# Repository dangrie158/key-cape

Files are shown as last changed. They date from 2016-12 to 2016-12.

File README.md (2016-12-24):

# KeyCape

a simple UI extension for your PC / Mac. 

KeyCape offers the following Hardware I/Os:

* Cherry MX Switch with LED
* Encoder with Button
* 4 general purpose LEDs

As the firmware is still in development I'm not sure yet how to implement all I/O in a good way. Probably a HID Keyboard with the Cherry Switch acting as a ESC button (so vim is usable again for the new Mac Books with touchbar) and the encoder as vol up/down.

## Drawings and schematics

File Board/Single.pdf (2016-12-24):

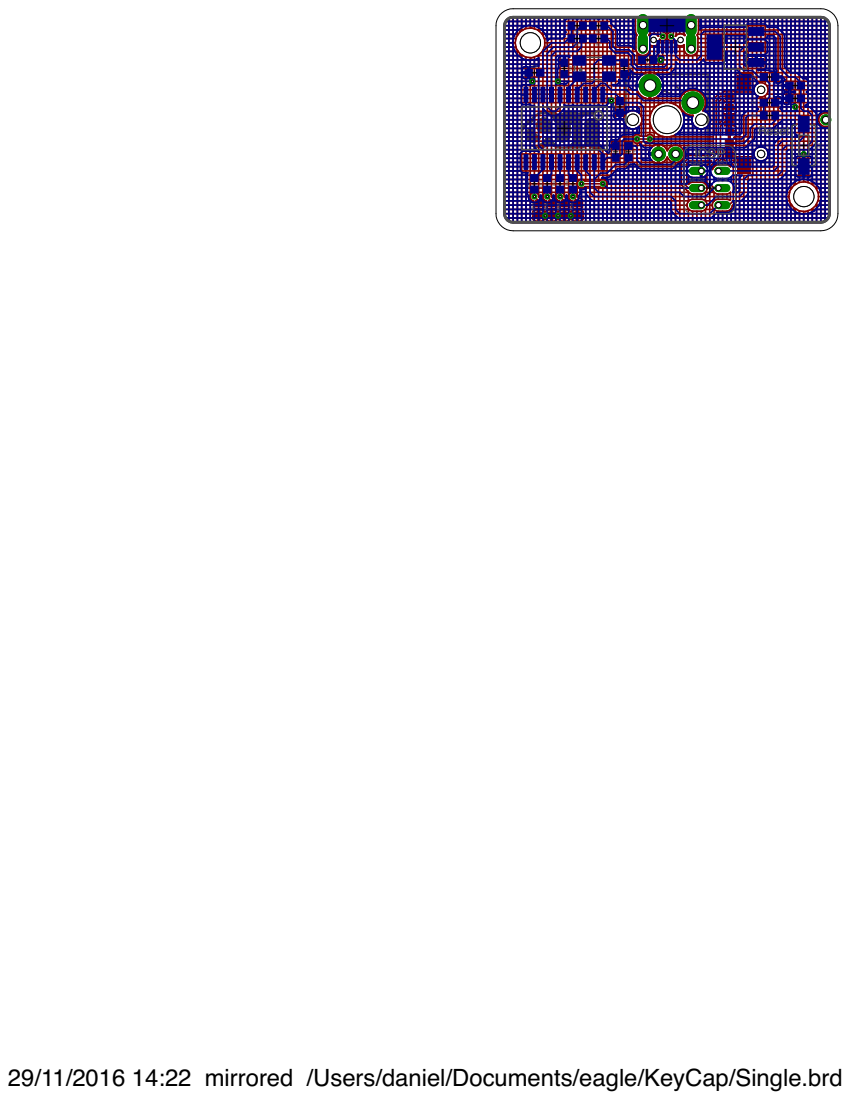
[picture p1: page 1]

RST MOSI VCC GND

29/11/2016 14:22 mirrored /Users/daniel/Documents/eagle/KeyCap/Single.brd

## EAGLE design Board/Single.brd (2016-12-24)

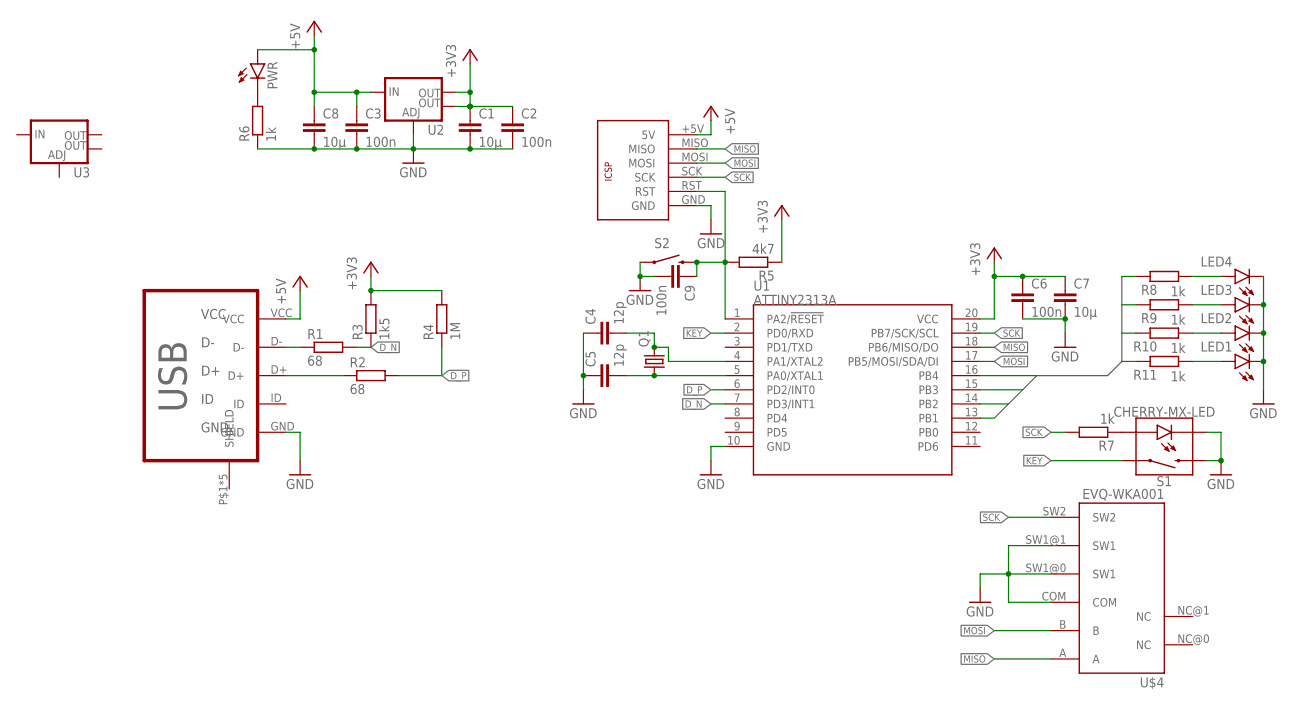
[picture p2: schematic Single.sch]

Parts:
C1, C7, C8: 10µ; C0603
C2, C3, C6, C9: 100n; C0603
C4, C5: 12p; C0603
LED1, LED2, LED3, LED4: LED0603; LED-0603
PWR: LED0603; LED-0603
Q1: CRYSTALCTS406; CTS406
R1, R2: 68; R0603
R3: 1k5; R0603
R4: 1M; R0603
R5: 4k7; R0603
R6, R7, R8, R9, R10, R11: 1k; R0603
S1: CHERRY-MX-LED
S2: SWITCH-MOMENTARY-2SMD-1101NE; TACTILE-SWITCH-1101NE
U1: ATTINY2313A; SOP20W
U2, U3: V_REG_LM1117SOT223; SOT223
U$1: ICSPTHROUGHHOLE; ICSP-THROUGHHOLE
U$2: MICRO-USB-B; MICRO_USB_4_LEGS
U$4: EVQ-WKA001

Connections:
+3V3: C1.1, C2.1, C6.1, C7.1, R3.2, R4.2, R5.1, U1.20 (VCC), U2.2 (OUT), U2.4 (OUT)
+5V: C3.1, C8.1, PWR.A, U2.3 (IN), U$1.+5V (5V), U$2.VCC
DUSB_N: R1.1, U$2.D-
DUSB_P: R2.1, U$2.D+
D_N: R1.2, R3.1, U1.7 (PD3/INT1)
D_P: R2.2, R4.1, U1.6 (PD2/INT0)
GND: C1.2, C2.2, C3.2, C4.1, C5.1, C6.2, C7.2, C8.2, C9.2, LED1.C, LED2.C, LED3.C, LED4.C, R6.1, S1.K (C), S1.S2, S2.1, U1.10 (GND), U2.1 (ADJ), U$1.GND, U$2.GND, U$4.COM, U$4.SW1@0 (SW1), U$4.SW1@1 (SW1)
KEY: S1.S1, U1.2 (PD0/RXD)
LED1: R11.2, U1.13 (PB1)
LED2: R10.2, U1.14 (PB2)
LED3: R9.2, U1.15 (PB3)
LED4: R8.2, U1.16 (PB4)
MISO: U1.18 (PB6/MISO/DO), U$1.MISO, U$4.A
MOSI: U1.17 (PB5/MOSI/SDA/DI), U$1.MOSI, U$4.B
unnamed: C4.2, Q1.3 (2), U1.4 (PA1/XTAL2)
unnamed: C5.2, Q1.1, U1.5 (PA0/XTAL1)
unnamed: PWR.C, R6.2
unnamed: C9.1, R5.2, S2.2, U1.1 (PA2/!RESET), U$1.RST
unnamed: R7.1, S1.A
unnamed: LED4.A, R8.1
unnamed: LED3.A, R9.1
unnamed: LED2.A, R10.1
unnamed: LED1.A, R11.1
SCK: R7.2, U1.19 (PB7/SCK/SCL), U$1.SCK, U$4.SW2

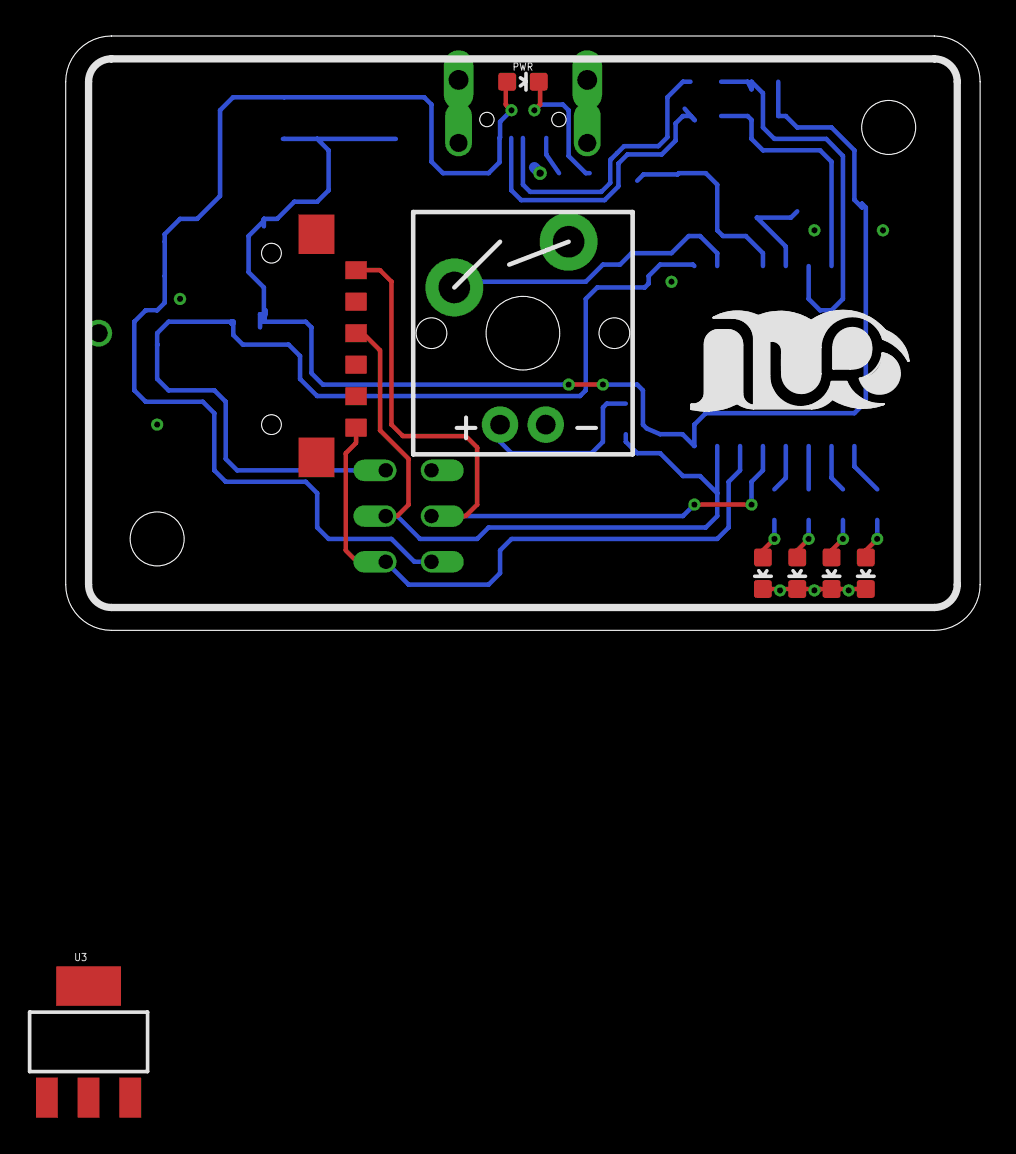
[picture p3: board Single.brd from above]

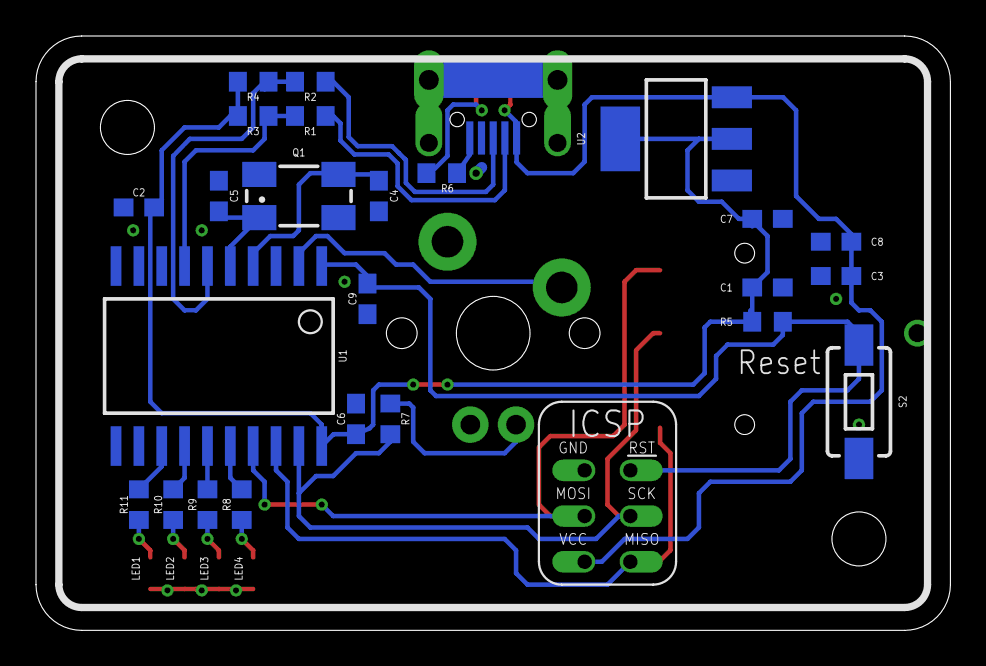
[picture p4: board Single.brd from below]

Board: 2 copper layers, 50.8 x 33.0 mm, 35 parts (26 on the bottom side), 24 nets.

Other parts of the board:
U$3: LOGO-SILKSCREEN

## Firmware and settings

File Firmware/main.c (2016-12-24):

#include <avr/interrupt.h>
#include <avr/io.h>
#include <avr/wdt.h>
#include <util/delay.h>

#include "pinmapping.h"

#include "clickencoder.h"
#include "usbdrv/usbdrv.h"

// ************************
// *** USB HID ROUTINES ***
// ************************

// From Frank Zhao's USB Business Card project
// http://www.frank-zhao.com/cache/usbbusinesscard_details.php
PROGMEM const char
    usbHidReportDescriptor[USB_CFG_HID_REPORT_DESCRIPTOR_LENGTH] = {
        0x05, 0x01, // USAGE_PAGE (Generic Desktop)
        0x09, 0x06, // USAGE (Keyboard)
        0xa1, 0x01, // COLLECTION (Application)
        0x75, 0x01, //   REPORT_SIZE (1)
        0x95, 0x08, //   REPORT_COUNT (8)
        0x05, 0x07, //   USAGE_PAGE (Keyboard)(Key Codes)
        0x19, 0xe0, //   USAGE_MINIMUM (Keyboard LeftControl)(224)
        0x29, 0xe7, //   USAGE_MAXIMUM (Keyboard Right GUI)(231)
        0x15, 0x00, //   LOGICAL_MINIMUM (0)
        0x25, 0x01, //   LOGICAL_MAXIMUM (1)
        0x81, 0x02, //   INPUT (Data,Var,Abs) ; Modifier byte
        0x95, 0x01, //   REPORT_COUNT (1)
        0x75, 0x08, //   REPORT_SIZE (8)
        0x81, 0x03, //   INPUT (Cnst,Var,Abs) ; Reserved byte
        0x95, 0x05, //   REPORT_COUNT (5)
        0x75, 0x01, //   REPORT_SIZE (1)
        0x05, 0x08, //   USAGE_PAGE (LEDs)
        0x19, 0x01, //   USAGE_MINIMUM (Num Lock)
        0x29, 0x05, //   USAGE_MAXIMUM (Kana)
        0x91, 0x02, //   OUTPUT (Data,Var,Abs) ; LED report
        0x95, 0x01, //   REPORT_COUNT (1)
        0x75, 0x03, //   REPORT_SIZE (3)
        0x91, 0x03, //   OUTPUT (Cnst,Var,Abs) ; LED report padding
        0x95, 0x06, //   REPORT_COUNT (6)
        0x75, 0x08, //   REPORT_SIZE (8)
        0x15, 0x00, //   LOGICAL_MINIMUM (0)
        0x25, 0x65, //   LOGICAL_MAXIMUM (101)
        0x05, 0x07, //   USAGE_PAGE (Keyboard)(Key Codes)
        0x19, 0x00, //   USAGE_MINIMUM (Reserved (no event indicated))(0)
        0x29, 0x65, //   USAGE_MAXIMUM (Keyboard Application)(101)
        0x81, 0x00, //   INPUT (Data,Ary,Abs)
        0xc0        // END_COLLECTION
};

typedef struct {
  uint8_t modifier;
  uint8_t reserved;
  uint8_t keycode[6];
} keyboardReport_t;

static keyboardReport_t keyboardReport;  // sent to PC
volatile static uint8_t ledState = 0xFF; // received from PC
static uint8_t idleRate;                 // repeat rate for keyboards

usbMsgLen_t usbFunctionSetup(uchar data[8]) {

  LED_PORT |= 1 << LED_KEY;
  usbRequest_t *rq = (void *)data;

  if ((rq->bmRequestType & USBRQ_TYPE_MASK) == USBRQ_TYPE_CLASS) {
    switch (rq->bRequest) {
    case USBRQ_HID_GET_REPORT: // send "no keys pressed" if asked here
      // wValue: ReportType (highbyte), ReportID (lowbyte)
      usbMsgPtr = (void *)&keyboardReport; // we only have this one
      keyboardReport.modifier = 0;
      keyboardReport.keycode[0] = 0;
      return sizeof(keyboardReport);
    case USBRQ_HID_SET_REPORT: // if wLength == 1, should be LED state
      return (rq->wLength.word == 1) ? USB_NO_MSG : 0;
    case USBRQ_HID_GET_IDLE: // send idle rate to PC as required by spec
      usbMsgPtr = &idleRate;
      return 1;
    case USBRQ_HID_SET_IDLE: // save idle rate as required by spec
      idleRate = rq->wValue.bytes[1];
      return 0;
    }
  }

  return 0; // by default don't return any data
}

usbMsgLen_t usbFunctionWrite(uint8_t *data, uchar len) {
  LED_PORT |= 1 << LED_KEY;
  // nice hack to save code, as it happens the LEDs are incorrect order and at
  // the right offset so we're able to just set the port status directly
  LED_PORT = data[0] & 0x0E;
  ledState = data[0];
  return 1; // Data read, not expecting more
}

void hardwareInit() {
  // set up the LEDs (all outputs), all initially off
  LED_DDR |=
      (1 << LED1) | (1 << LED2) | (1 << LED3) | (1 << LED4) | (1 << LED_KEY);
  LED_PORT &=
      ~((1 << LED1) | (1 << LED2) | (1 << LED3) | (1 << LED4) | (1 << LED_KEY));

  // set up the encoder (all inputs with pullups)
  // ENC_DDR &= ~((1 << ENC_A) | ~(1 << ENC_B) | ~(1 << ENC_BTN));
  // ENC_PORT |= (1 << ENC_A) | (1 << ENC_B) | (1 << ENC_BTN);

  // set up the keyswitch button (input with pullup)
  KEY_DDR &= ~(1 << KEY);
  KEY_PORT |= (1 << KEY);

  // set up the USB lines (inputs without pullups)
  USB_DDR &= ~((1 << USB_N) | (1 << USB_P));
  USB_PORT &= ~((1 << USB_N) | (1 << USB_P));
}

/*void timerInit() {
  // setup Timer 1 to trigger an interrupt every 1ms
  // see http://www.atmel.com/Images/Atmel-2543-AVR-ATtiny2313_Datasheet.pdf (p.
  // 106)
  // Mode 4: CTC
  TCCR1A &= ~((1 << WGM11) | (1 << WGM10));
  TCCR1B |= (1 << WGM12);
  TCCR1B &= ~(1 << WGM13);

  // Prescaler 1/1024
  TCCR1B |= (1 << CS11);

  // enable interrupt in output compare match
  TIMSK |= (1 << OCIE1A);

  // F_CPU = 12MHz
  // F_CPU / Prescaler = 12MHz / 8 = 1.5MHz
  // 1.5 MHz / 1500 = 1kHz
  OCR1A = 1500;
}

// Timer 1 interrupt vector
ISR(TIMER1_COMPA_vect) { encoder_service(); }

*/

// Now only supports letters 'a' to 'z' and 0 (NULL) to clear buttons
void buildReport(uchar send_key) {
  keyboardReport.modifier = 0;

  keyboardReport.modifier = 5;

  if (send_key >= 'a' && send_key <= 'z')
    keyboardReport.keycode[0] = 4 + (send_key - 'a');
  else
    keyboardReport.keycode[0] = 0;
}

int main() {
  hardwareInit();
  // timerInit();
  encoder_init();

  // clear report initially
  for (int i = 0; i < sizeof(keyboardReport); i++) {
    ((uchar *)&keyboardReport)[i] = 0;
  }

  wdt_enable(WDTO_1S); // enable 1s watchdog timer

  // enforce re-enumeration
  usbDeviceDisconnect();
  // wait 500 ms
  for (int i = 0; i < 250; i++) {
    wdt_reset(); // keep the watchdog happy
    _delay_ms(2);
  }
  usbDeviceConnect();

  usbInit();

  TCCR0B |= (1 << CS01); // timer 0 at clk/8 will generate randomness

  sei(); // Enable interrupts after re-enumeration

  while (1) {
    wdt_reset(); // keep the watchdog happy
    usbPoll();
    /*int16_t value = encoder_getValue();
    if (value % 8 == 0) {
      LED_PORT |= 1 << LED1;
    } else {
      LED_PORT &= ~(1 << LED1);
    }*/

    // characters are sent when messageState == STATE_SEND and after receiving
    // the initial LED state from PC (good way to wait until device is
    // recognized)
    /*if (usbInterruptIsReady()) {
      switch (state) {
      case STATE_SEND_KEY:

        state = STATE_RELEASE_KEY; // release next
        break;
      case STATE_RELEASE_KEY:
        buildReport(NULL);
        state = STATE_WAIT; // go back to waiting
        break;
      default:
        state = STATE_WAIT; // should not happen
      }

    // start sending
  }*/
    /*if (usbInterruptIsReady()) {
      buildReport('x');
      usbSetInterrupt((void *)&keyboardReport, sizeof(keyboardReport));
    }*/
  }

  return 0;
}

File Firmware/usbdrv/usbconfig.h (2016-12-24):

/* Name: usbconfig.h
 * Project: V-USB, virtual USB port for Atmel's(r) AVR(r) microcontrollers
 * Author: Christian Starkjohann
 * Creation Date: 2005-04-01
 * Tabsize: 4
 * Copyright: (c) 2005 by OBJECTIVE DEVELOPMENT Software GmbH
 * License: GNU GPL v2 (see License.txt), GNU GPL v3 or proprietary
 * (CommercialLicense.txt)
 */

#ifndef __usbconfig_h_included__
#define __usbconfig_h_included__

/*
General Description:
This file is an example configuration (with inline documentation) for the USB
driver. It configures V-USB for USB D+ connected to Port D bit 2 (which is
also hardware interrupt 0 on many devices) and USB D- to Port D bit 4. You may
wire the lines to any other port, as long as D+ is also wired to INT0 (or any
other hardware interrupt, as long as it is the highest level interrupt, see
section at the end of this file).
+ To create your own usbconfig.h file, copy this file to your project's
+ firmware source directory) and rename it to "usbconfig.h".
+ Then edit it accordingly.
*/

/* ---------------------------- Hardware Config ---------------------------- */

#define USB_CFG_IOPORTNAME D
/* This is the port where the USB bus is connected. When you configure it to
 * "B", the registers PORTB, PINB and DDRB will be used.
 */
#define USB_CFG_DMINUS_BIT 3
/* This is the bit number in USB_CFG_IOPORT where the USB D- line is connected.
 * This may be any bit in the port.
 */
#define USB_CFG_DPLUS_BIT 2
/* This is the bit number in USB_CFG_IOPORT where the USB D+ line is connected.
 * This may be any bit in the port. Please note that D+ must also be connected
 * to interrupt pin INT0! [You can also use other interrupts, see section
 * "Optional MCU Description" below, or you can connect D- to the interrupt, as
 * it is required if you use the USB_COUNT_SOF feature. If you use D- for the
 * interrupt, the USB interrupt will also be triggered at Start-Of-Frame
 * markers every millisecond.]
 */
#define USB_CFG_CLOCK_KHZ (F_CPU / 1000)
/* Clock rate of the AVR in kHz. Legal values are 12000, 12800, 15000, 16000,
 * 16500, 18000 and 20000. The 12.8 MHz and 16.5 MHz versions of the code
 * require no crystal, they tolerate +/- 1% deviation from the nominal
 * frequency. All other rates require a precision of 2000 ppm and thus a
 * crystal!
 * Since F_CPU should be defined to your actual clock rate anyway, you should
 * not need to modify this setting.
 */
#define USB_CFG_CHECK_CRC 0
/* Define this to 1 if you want that the driver checks integrity of incoming
 * data packets (CRC checks). CRC checks cost quite a bit of code size and are
 * currently only available for 18 MHz crystal clock. You must choose
 * USB_CFG_CLOCK_KHZ = 18000 if you enable this option.
 */

/* ----------------------- Optional Hardware Config ------------------------ */

/* #define USB_CFG_PULLUP_IOPORTNAME   D */
/* If you connect the 1.5k pullup resistor from D- to a port pin instead of
 * V+, you can connect and disconnect the device from firmware by calling
 * the macros usbDeviceConnect() and usbDeviceDisconnect() (see usbdrv.h).
 * This constant defines the port on which the pullup resistor is connected.
 */
/* #define USB_CFG_PULLUP_BIT          4 */
/* This constant defines the bit number in USB_CFG_PULLUP_IOPORT (defined
 * above) where the 1.5k pullup resistor is connected. See description
 * above for details.
 */

/* --------------------------- Functional Range ---------------------------- */
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

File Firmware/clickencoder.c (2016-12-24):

// ----------------------------------------------------------------------------
// Rotary Encoder Driver with Acceleration
// Supports Click, DoubleClick, Long Click
//
// (c) 2010 karl@pitrich.com
// (c) 2014 karl@pitrich.com
//
// Timer-based rotary encoder logic by Peter Dannegger
// http://www.mikrocontroller.net/articles/Drehgeber
// ----------------------------------------------------------------------------

#include "clickencoder.h"
#include "pinmapping.h"

int16_t delta;
int16_t last;

void encoder_init() {

  delta = 0;
  last = 0;

  if (ENC_PIN & (1 << ENC_A)) {
    last = 3;
  }

  if (ENC_PIN & (1 << ENC_B)) {
    last ^= 1;
  }
}

int16_t encoder_getValue(void) {
  int8_t curr = 0;

  if (ENC_PIN & (1 << ENC_A)) {
    curr = 3;
  }

  if (ENC_PIN & (1 << ENC_B)) {
    curr ^= 1;
  }

  int8_t diff = last - curr;

  if (diff & 1) // bit 0 = step
  {
    last = curr;
    delta += (diff & 2) - 1; // bit 1 = direction (+/-)
  }
  /*if (steps == 2)
    delta = val & 1;
  else if (steps == 4)*/
  delta = delta & 3;
  /*else
    delta = 0; // default to 1 step per notch


  /*if (steps == 4)*/
  delta >>= 2;
  /*if (steps == 2)
    val >>= 1;*/

  return delta;
}

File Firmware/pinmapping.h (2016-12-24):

// ***********************************************************
// ***                    USB HID KEY DEFS                 ***
// *** http://www.usb.org/developers/hidpage/Hut1_12v2.pdf ***
// ***********************************************************
#define KEY_ESCAPE 0x29
#define KEY_MUTE 0x7F
#define KEY_VOL_DOWN 0x81
#define KEY_VOL_UP 0x80

// ***********************************************************
// ***                    USB HID LED DEFS                 ***
// *** http://www.usb.org/developers/hidpage/Hut1_12v2.pdf ***
// ***********************************************************
#define NUM_LOCK 0x01
#define CAPS_LOCK 0x02
#define SCROLL_LOCK 0x04

// ***********************************************************
// ***                      PIN MAPPING                    ***
// ***********************************************************
#define LED1 PB1
#define LED2 PB2
#define LED3 PB3
#define LED4 PB4
#define LED_KEY PB7
#define LED_DDR DDRB
#define LED_PORT PORTB

#define ENC_A PB6
#define ENC_B PB5
#define ENC_BTN PB7
#define ENC_DDR DDRB
#define ENC_PIN PINB
#define ENC_PORT PORTB

#define KEY PD0
#define KEY_DDR DDRD
#define KEY_PIN PIND
#define KEY_PORT PORTD

#define USB_DDR DDRD
#define USB_PORT PORTD
#define USB_PIN PIND
#define USB_P PD2
#define USB_N PD3

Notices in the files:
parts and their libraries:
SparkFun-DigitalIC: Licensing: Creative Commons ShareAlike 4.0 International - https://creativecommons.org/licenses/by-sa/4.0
